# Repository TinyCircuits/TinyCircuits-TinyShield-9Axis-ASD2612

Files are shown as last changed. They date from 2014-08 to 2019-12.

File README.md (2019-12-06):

# TinyCircuits TinyShield 9-Axis Board
# ASD2612 Rev3

WARNING: This repo is obsolete, the current 9-Axis TinyShield has been moved to the Combo Sensor TinyShield repo found here: https://github.com/TinyCircuits/TinyCircuits-TinyShield-Sensor-ASD2511

These are the design files for the TinyCircuits ASD2612 Rev 3 PCB.  This is a TinyShield board (20mm x 20mm) that has a 9-Axis IMU.

Format is in Cadsoft Eagle format - Eagle version 6.2 was used for the original design.

# License:

Design by TinyCircuits.
All design files are released under the Creative Commons Attribution Share-Alike 3.0 License, see the following link for details: http://creativecommons.org/licenses/by-sa/3.0

All text above must be included in any redistribution or derived design

This project uses designs and concepts developed as part of the Arduino project and the LilyPad project.  The TinyCircuits design files themselves (schematics, PCB and libraries) are not directly derived from these works' design files and have been created new, however the concepts and basic architecture behind the TinyDuino and TinyLily products are derived and we thank the hard work of the organizations below for their contributions to open-source hardware:
  
Original Arduino Uno Design by Team Arduino

LilyPad Arduino Design by Leah Buechley and Sparkfun Electronics

Please support the open-source hardware community

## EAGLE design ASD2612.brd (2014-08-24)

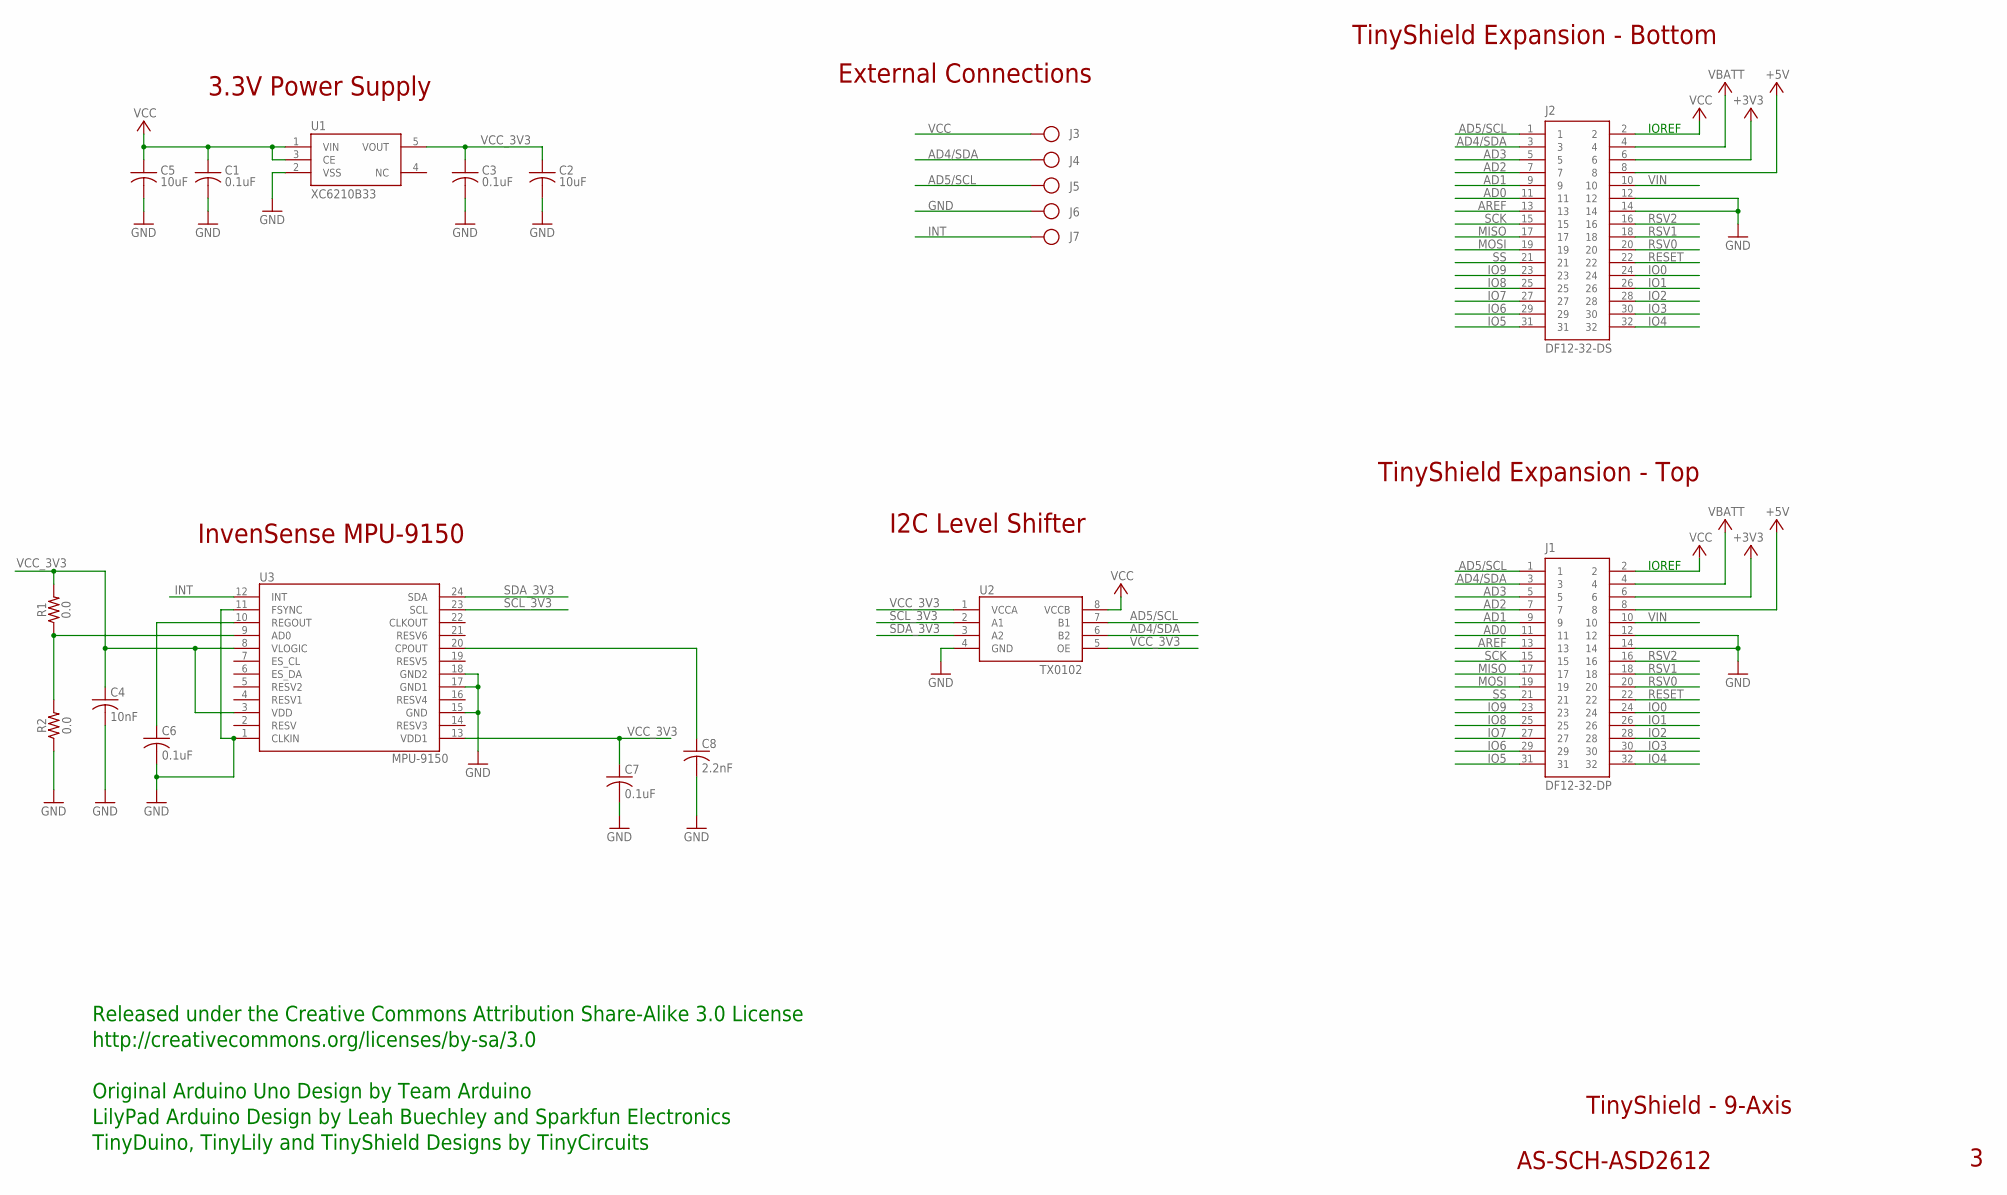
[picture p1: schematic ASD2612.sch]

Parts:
C1, C3: 0.1uF; C0402; PARTNO AS-ITM-00008
C2: 10uF; C0805; PARTNO AS-ITM-00045
C4: 10nF; C0402
C5: 10uF; C0805
C6, C7: 0.1uF; C0402
C8: 2.2nF; C0402
J1: DF12-32-DP; PARTNO AS-ITM-00015
J2: DF12-32-DS; PARTNO AS-ITM-00012
J3, J4, J5, J6, J7: PIN_1X.1"; 1X.1"
R1: 0.0; 0402
R2: AS-ITM-000760402_SHORT; 0402_SHORT
U1: XC6210B33; SOT-25
U2: TX0102; DQE(R-PX2SON-N8)
U3: MPU-9150

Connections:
+3V3: J1.6, J2.6
+5V: J1.8, J2.8
AD0: J1.11, J2.11
AD1: J1.9, J2.9
AD2: J1.7, J2.7
AD3: J1.5, J2.5
AD4/SDA: J1.3, J2.3, J4.1, U2.6 (B2)
AD5/SCL: J1.1, J2.1, J5.1, U2.7 (B1)
AREF: J1.13, J2.13
GND: C1.2, C2.2, C3.2, C4.2, C5.2, C6.2, C7.2, C8.2, J1.12, J1.14, J2.12, J2.14, J6.1, R2.1, U1.2 (VSS), U2.4 (GND), U3.1 (CLKIN), U3.11 (FSYNC), U3.15 (GND), U3.17 (GND1), U3.18 (GND2)
INT: J7.1, U3.12 (INT)
IO0: J1.24, J2.24
IO1: J1.26, J2.26
IO2: J1.28, J2.28
IO3: J1.30, J2.30
IO4: J1.32, J2.32
IO5: J1.31, J2.31
IO6: J1.29, J2.29
IO7: J1.27, J2.27
IO8: J1.25, J2.25
IO9: J1.23, J2.23
MISO: J1.17, J2.17
MOSI: J1.19, J2.19
unnamed: C8.1, U3.20 (CPOUT)
unnamed: C6.1, U3.10 (REGOUT)
unnamed: R1.1, R2.2, U3.9 (AD0)
RESET: J1.22, J2.22
RSV0: J1.20, J2.20
RSV1: J1.18, J2.18
RSV2: J1.16, J2.16
SCK: J1.15, J2.15
SCL_3V3: U2.2 (A1), U3.23 (SCL)
SDA_3V3: U2.3 (A2), U3.24 (SDA)
SS: J1.21, J2.21
VBATT: J1.4, J2.4
VCC: C1.1, C5.1, J1.2, J2.2, J3.1, U1.1 (VIN), U1.3 (CE), U2.8 (VCCB)
VCC_3V3: C2.1, C3.1, C4.1, C7.1, R1.2, U1.5 (VOUT), U2.1 (VCCA), U2.5 (OE), U3.3 (VDD), U3.8 (VLOGIC), U3.13 (VDD1)
VIN: J1.10, J2.10

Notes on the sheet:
TinyShield Expansion - Bottom
TinyShield - 9-Axis
AS-SCH-ASD2612
TinyShield Expansion - Top
IOREF
Released under the Creative Commons Attribution Share-Alike 3.0 License
http://creativecommons.org/licenses/by-sa/3.0
LilyPad Arduino Design by Leah Buechley and Sparkfun Electronics
TinyDuino, TinyLily and TinyShield Designs by TinyCircuits
Original Arduino Uno Design by Team Arduino
External Connections
3.3V Power Supply
I2C Level Shifter
InvenSense MPU-9150
0.0

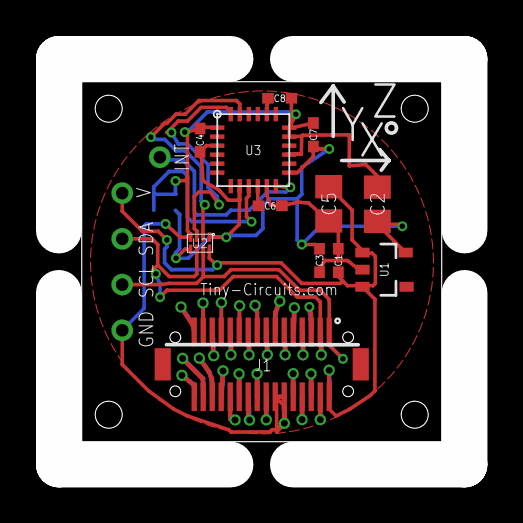
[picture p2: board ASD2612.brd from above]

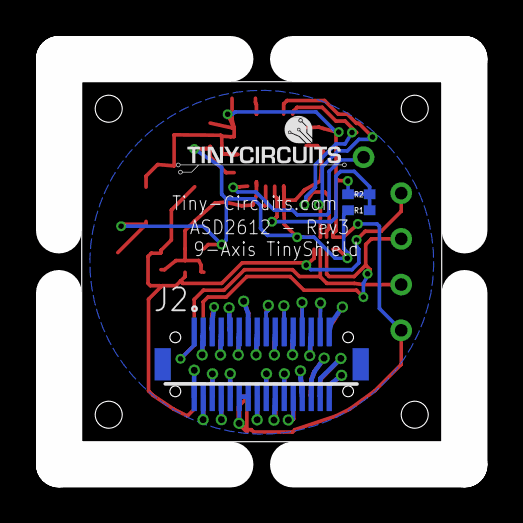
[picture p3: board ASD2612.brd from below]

Board: 2 copper layers, 20.0 x 20.0 mm, 21 parts (3 on the bottom side), 38 nets.

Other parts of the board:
U$1: DOCFIELD-TINYCIRCUITS-PCB
